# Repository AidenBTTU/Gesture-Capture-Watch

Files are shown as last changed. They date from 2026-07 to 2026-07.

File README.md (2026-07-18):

# Gesture-Capture-Watch
A wristband-mounted gesture recognition system built around an STM32F411, IMU, and OLED display, with USB-C battery charging and ESD-protected I/O. Includes full PCB design, manufacturing files, and firmware for real-time motion capture and on-device gesture classification via TFLite Micro. 

# Hardware Overview
- **MCU:** [STM32F411CEU6](https://www.st.com/en/microcontrollers-microprocessors/stm32f411.html), high Flash and SRAM to run TFLite model
- **IMU:** [LSM6DSOX](https://www.st.com/en/mems-and-sensors/lsm6dsox.html), industry standard, small form factor, low power consumption, includes a machine learning core for pre-processing
- **Power System:**
  - **Interface:** [USB-C](https://www.digikey.com/en/products/detail/gct/USB4105-GF-A-120/14559037), flexible power delivery, industry standard
  - **ESD Protection:** [USBLC6-2SC6](https://www.digikey.com/en/products/detail/stmicroelectronics/USBLC6-2SC6/1040559), industry standard
  - **Li-ion Battery Charger:** [BQ24092DGQR](https://www.ti.com/product/BQ24092/part-details/BQ24092DGQR), short circuit protection, variable charging
  - **Linear Regulator:** [TPS7A0533PDBZ](https://www.ti.com/product/TPS7A05/part-details/TPS7A0533PDBZT), low drop-out
- **Display:** 0.96" OLED display with SSD1306 chipset

# Software Overview (WIP)
- **Programming Environment:** STM32 programmed and configured via STLink V2. STM32CubeIDE was used to write code in C, and STM32CubeMX was used to set up peripherals and the external high-speed clock.
- **Libraries:** [u8g2](https://github.com/olikraus/u8g2), [lsm6dsox](https://github.com/STMicroelectronics/lsm6dsox-pid)

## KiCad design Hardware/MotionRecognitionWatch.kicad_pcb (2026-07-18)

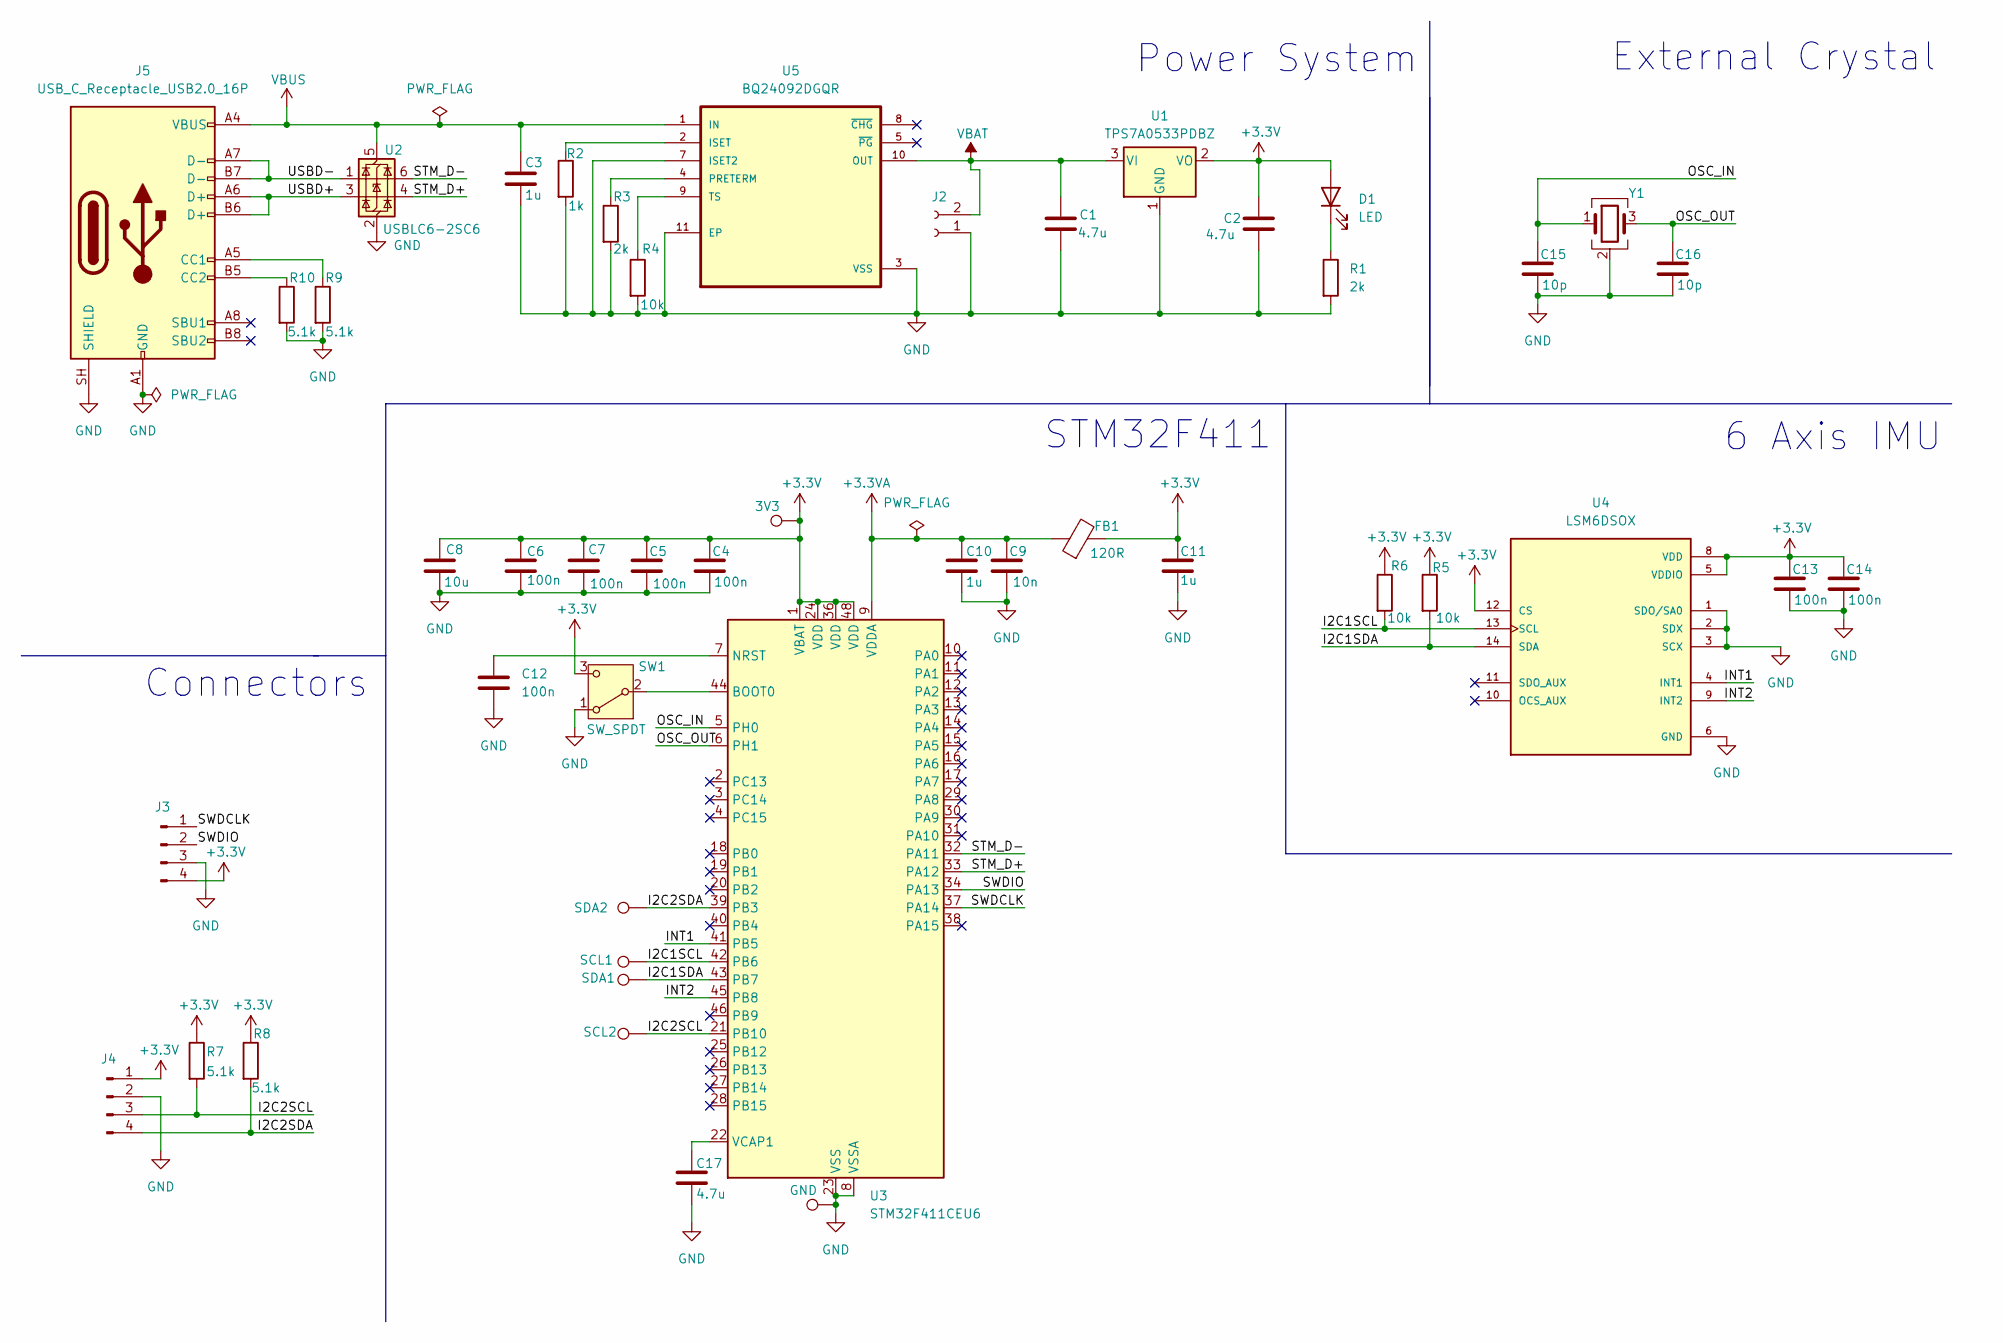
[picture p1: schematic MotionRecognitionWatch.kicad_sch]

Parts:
3V3: TestPoint; TestPoint_Pad_2.0x2.0mm
C1, C2, C17: 4.7u; C_0603_1608Metric
C3, C10, C11: 1u; C_0603_1608Metric
C4, C5, C6, C7, C12, C13, C14: 100n; C_0402_1005Metric
C8: 10u; C_0603_1608Metric
C9: 10n; C_0402_1005Metric
C15, C16: 10p; C_0402_1005Metric
D1: LED; LED_0603_1608Metric
FB1: 120R; L_0603_1608Metric
GND: TestPoint; TestPoint_Pad_2.0x2.0mm
J2: Conn_01x02_Socket; JST_PH_S2B-PH-K_1x02_P2.00mm_Horizontal
J3, J4: Conn_01x04_Pin; PinHeader_1x04_P2.54mm_Vertical
J5: USB_C_Receptacle_USB2.0_16P; USB_C_Receptacle_GCT_USB4105-xx-A_16P_TopMnt_Horizontal
R1, R3: 2k; R_0402_1005Metric
R2: 1k; R_0402_1005Metric
R4, R5, R6: 10k; R_0402_1005Metric
R7, R8, R9, R10: 5.1k; R_0402_1005Metric
SCL1, SCL2: TestPoint; TestPoint_Pad_2.0x2.0mm
SDA1: TestPoint; TestPoint_Pad_2.0x2.0mm
SDA2: TestPoint_Pad_2.0x2.0mm
SW1: SW_SPDT; SW_SPDT_PCM12
U1: TPS7A0533PDBZ; SOT-23
U2: USBLC6-2SC6; SOT-23-6
U3: STM32F411CEU6; QFN-48-1EP_7x7mm_P0.5mm_EP5.6x5.6mm
U4: LSM6DSOX; PQFN50P250X300X86-14N; PARTREV 3.0
U5: BQ24092DGQR; IC_XTR111AIDGQR
Y1: Crystal_GND24; Crystal_SMD_3225-4Pin_3.2x2.5mm

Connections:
+3.3V: 3V3.1 (1_1), C2.1, C4.1, C5.1, C6.1, C7.1, C8.1, C11.1, C13.1, C14.1, D1.2 (A), FB1.2, J3.4, J4.1, R5.1, R6.1, R7.1, R8.1, SW1.3 (C), U1.2 (VO), U3.1 (VBAT), U3.24 (VDD), U3.36 (VDD), U3.48 (VDD), U4.5 (VDDIO), U4.8 (VDD), U4.12 (CS); also elsewhere on the board
+3.3VA: C9.1, C10.1, FB1.1, U3.9 (VDDA)
/I2C1SCL: R6.2, SCL1.1 (1_1), U3.42 (PB6), U4.13 (SCL); also elsewhere on the board
/I2C1SDA: R5.2, SDA1.1 (1_1), U3.43 (PB7), U4.14 (SDA); also elsewhere on the board
/I2C2SCL: J4.3, R7.2, SCL2.1 (1_1), U3.21 (PB10)
/I2C2SDA: J4.4, R8.2, SDA2.1 (1_1), U3.39 (PB3)
/INT1: U3.41 (PB5), U4.4 (INT1); also elsewhere on the board
/INT2: U3.45 (PB8), U4.9 (INT2); also elsewhere on the board
/OSC_IN: C15.1, U3.5 (PH0), Y1.1
/OSC_OUT: C16.1, U3.6 (PH1), Y1.3
/STM_D+: U2.4 (I/O2), U3.33 (PA12)
/STM_D-: U2.6 (I/O1), U3.32 (PA11)
/SWDCLK: J3.1, U3.37 (PA14)
/SWDIO: J3.2, U3.34 (PA13)
/USBD+: J5.A6 (D+), J5.B6 (D+), U2.3 (I/O2)
/USBD-: J5.A7 (D-), J5.B7 (D-), U2.1 (I/O1)
GND: C1.2, C2.2, C3.2, C4.2, C5.2, C6.2, C7.2, C8.2, C9.2, C10.2, C11.2, C12.2, C13.2, C14.2, C15.2, C16.2, C17.2, GND.1 (1_1), J2.1, J3.3, J4.2, J5.A1 (GND), J5.A12 (GND), J5.B1 (GND), J5.B12 (GND), J5.SH (SHIELD), R1.2, R2.2, R3.2, R4.2, R9.2, R10.2, SW1.1 (A), U1.1 (GND), U2.2 (GND), U3.8 (VSSA), U3.23 (VSS), U3.35 (VSS), U3.47 (VSS), U3.49 (VSS), U4.1 (SDO/SA0), U4.2 (SDX), U4.3 (SCX), U4.6 (GND), U4.7 (GND), U5.3 (VSS), U5.7 (ISET2), U5.11 (EP), U5.12, U5.13, U5.14, U5.15, U5.16, Y1.2 (G), Y1.4 (G); also elsewhere on the board
unnamed: D1.1 (K), R1.1
unnamed: J5.A5 (CC1), R9.1
unnamed: J5.B5 (CC2), R10.1
unnamed 20: SW1.2 (B), U3.44 (BOOT0); also elsewhere on the board
unnamed: C12.1, U3.7 (NRST)
unnamed: C17.1, U3.22 (VCAP1)
unnamed: R2.1, U5.2 (ISET)
unnamed: R3.1, U5.4 (PRETERM)
unnamed: R4.1, U5.9 (TS)
VBAT: C1.1, J2.2, U1.3 (VI), U5.10 (OUT)
VBUS: C3.1, J5.A4 (VBUS), J5.A9 (VBUS), J5.B4 (VBUS), J5.B9 (VBUS), U2.5 (VBUS), U5.1 (IN)

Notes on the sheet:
STM32F411
Power System
Connectors
6 Axis IMU
External Crystal

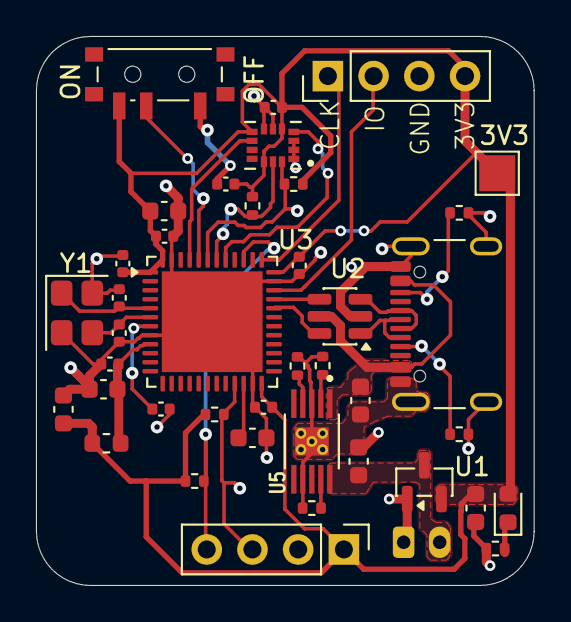
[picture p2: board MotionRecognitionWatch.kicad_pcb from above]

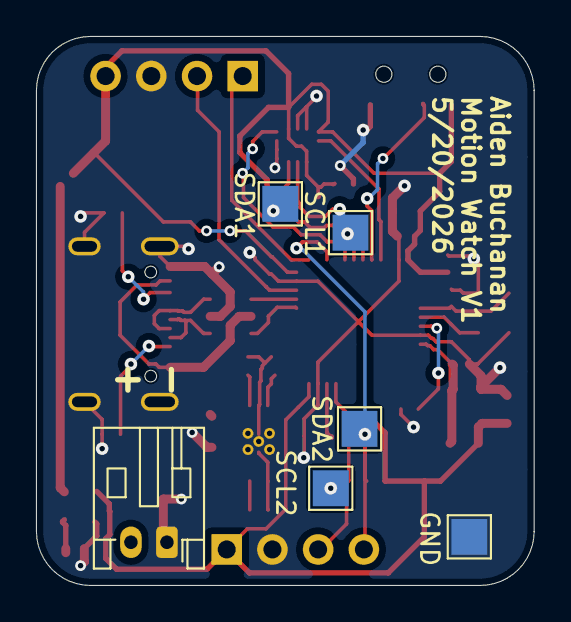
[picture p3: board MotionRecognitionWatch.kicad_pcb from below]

Board: 2 copper layers, 27.6 x 30.5 mm, 46 parts (6 on the bottom side), 28 nets.

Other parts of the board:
ON: SW_SPDT; SW_SPDT_PCM12
U6: LSM6DSOX; PQFN50P250X300X86-14N

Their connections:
+3.3V: ON.3 (C), U6.5 (VDDIO), U6.8 (VDD), U6.12 (CS); also elsewhere on the board
/I2C1SCL: U6.13 (SCL); also elsewhere on the board
/I2C1SDA: U6.14 (SDA); also elsewhere on the board
/INT1: U6.4 (INT1); also elsewhere on the board
/INT2: U6.9 (INT2); also elsewhere on the board
GND: ON.1 (A), U6.1 (SDO/SA0), U6.2 (SDX), U6.3 (SCX), U6.6 (GND), U6.7 (GND); also elsewhere on the board
unnamed 20: ON.2 (B); also elsewhere on the board

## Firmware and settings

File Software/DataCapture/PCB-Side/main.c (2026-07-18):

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
/* Includes ------------------------------------------------------------------*/
#include "main.h"
#include "usb_device.h"

/* USER CODE BEGIN Includes */
#include "lsm6dsox_reg.h"
#include "usbd_cdc_if.h"
#include <stdio.h>
#include <stdint.h>
#include <stddef.h>
#include <math.h>
#include <string.h>
#include "u8g2.h"
/* USER CODE END Includes */

I2C_HandleTypeDef hi2c1;
I2C_HandleTypeDef hi2c2;

void SystemClock_Config(void);
static void MX_GPIO_Init(void);
static void MX_I2C1_Init(void);
static void MX_I2C2_Init(void);
/* USER CODE BEGIN PFP */
#define LSM6DSOX_I2C_ADDR (0x6A << 1)
#define DISPLAY_ADDR (0x3C << 1)

/* USER CODE END PFP */

/* USER CODE BEGIN 0 */
static uint8_t i2c_tx_buf[256];
static uint8_t i2c_tx_buf_idx = 0;
uint8_t u8x8_byte_stm32_hw_i2c(u8x8_t *u8x8, uint8_t msg, uint8_t arg_int, void *arg_ptr)
{
	uint8_t *data;
	    switch(msg)
	    {
	        case U8X8_MSG_BYTE_INIT:
	            break; // HAL I2C already initialized in MX_I2C2_Init

	        case U8X8_MSG_BYTE_START_TRANSFER:
	            i2c_tx_buf_idx = 0;
	            break;

	        case U8X8_MSG_BYTE_SEND:
	            data = (uint8_t *)arg_ptr;
	            while(arg_int > 0) {
	                i2c_tx_buf[i2c_tx_buf_idx++] = *data++;
	                arg_int--;
	            }
	            break;

	        case U8X8_MSG_BYTE_END_TRANSFER:
	        	HAL_I2C_Master_Transmit(
	                &hi2c2,
	                DISPLAY_ADDR,
	                i2c_tx_buf,
	                i2c_tx_buf_idx,
	                1000    
				);
	            break;

	        default:
	            return 0;
	    }
	    return 1;
}

uint8_t u8x8_delay_and_gpio(u8x8_t *u8x8, uint8_t msg, uint8_t arg_int, void *arg_ptr) {
switch(msg)
    {
        case U8X8_MSG_GPIO_AND_DELAY_INIT:
            break; 

        case U8X8_MSG_GPIO_RESET:
            break; 

        case U8X8_MSG_DELAY_MILLI:
            HAL_Delay(arg_int);
            break;

        case U8X8_MSG_DELAY_10MICRO:
            // 72MHz → ~720 cycles per 10µs; loop overhead ~5 cyc/iter → 144 iters
            for(uint8_t d = 0; d < arg_int; d++)
                for(volatile uint32_t i = 0; i < 144; i++) __NOP();
            break;

        case U8X8_MSG_DELAY_100NANO:
            for(uint8_t d = 0; d < arg_int; d++) {
                __NOP(); __NOP(); __NOP(); __NOP(); __NOP(); __NOP(); __NOP();
            }
            break;

        default:
            return 0;
    }
    return 1;
}
/* USER CODE END 0 */

/**
  * @brief  The application entry point.
  * @retval int
  */
int main(void)
{

  /* MCU Configuration--------------------------------------------------------*/

  /* Reset of all peripherals, Initializes the Flash interface and the Systick. */
  HAL_Init();

  /* Configure the system clock */
  SystemClock_Config();

  /* Initialize all configured peripherals */
  MX_GPIO_Init();
  MX_I2C1_Init();
  MX_I2C2_Init();
  MX_USB_DEVICE_Init();
  /* USER CODE BEGIN 2 */
  stmdev_ctx_t dev_ctx;

  dev_ctx.write_reg = platform_write;
  dev_ctx.read_reg = platform_read;
  dev_ctx.handle = &hi2c1;


  /* USER CODE END 2 */

  /* Infinite loop */
  /* USER CODE BEGIN WHILE */
  uint8_t whoami;
  lsm6dsox_device_id_get(&dev_ctx, &whoami);
  lsm6dsox_reset_set(&dev_ctx, PROPERTY_ENABLE);

  uint8_t rst;
  do {
      lsm6dsox_reset_get(&dev_ctx, &rst);
  } while (rst);

  lsm6dsox_block_data_update_set(&dev_ctx, PROPERTY_ENABLE);

  lsm6dsox_xl_data_rate_set(
      &dev_ctx,
      LSM6DSOX_XL_ODR_104Hz);

  lsm6dsox_xl_full_scale_set(
      &dev_ctx,
      LSM6DSOX_2g);

  lsm6dsox_gy_data_rate_set(
      &dev_ctx,
      LSM6DSOX_GY_ODR_104Hz);

  lsm6dsox_gy_full_scale_set(
      &dev_ctx,
      LSM6DSOX_250dps);



  u8g2_t u8g2; 
  u8g2_Setup_ssd1306_i2c_128x64_noname_f(&u8g2, U8G2_R0, u8x8_byte_stm32_hw_i2c, u8x8_delay_and_gpio);
  u8g2_InitDisplay(&u8g2);
  u8g2_SetPowerSave(&u8g2, 0);
  u8g2_SetFont(&u8g2, u8g2_font_6x10_tf);   
  u8g2_ClearBuffer(&u8g2);

  HAL_Delay(500);

  volatile int16_t gyro_raw[3];
  volatile int16_t accel_raw[3];

  while (1)
  {
    /* USER CODE END WHILE */

    /* USER CODE BEGIN 3 */

	  //Check if ready to receive data
      uint8_t xl_ready;
      uint8_t gy_ready;
      lsm6dsox_xl_flag_data_ready_get(&dev_ctx, &xl_ready);
      lsm6dsox_gy_flag_data_ready_get(&dev_ctx, &gy_ready);

      if (xl_ready && gy_ready)
      {
    	  //Poll values, pass into USB
          lsm6dsox_acceleration_raw_get(&dev_ctx, (int16_t *)accel_raw);
          lsm6dsox_angular_rate_raw_get(&dev_ctx, (int16_t *)gyro_raw);

          int32_t ax = ((int32_t)accel_raw[0] * 61) / 1000;
          int32_t ay = ((int32_t)accel_raw[1] * 61) / 1000;
          int32_t az = ((int32_t)accel_raw[2] * 61) / 1000;

          char line[24];
          u8g2_ClearBuffer(&u8g2);

          snprintf(line, sizeof(line), "AX: %4d mg", (int)ax);
          u8g2_DrawStr(&u8g2, 0, 12, line);

          snprintf(line, sizeof(line), "AY: %4d mg", (int)ay);
          u8g2_DrawStr(&u8g2, 0, 26, line);

          snprintf(line, sizeof(line), "AZ: %4d mg", (int)az);
          u8g2_DrawStr(&u8g2, 0, 40, line);

          u8g2_SendBuffer(&u8g2);
          char tx_buf[64];
          int len = snprintf(tx_buf, sizeof(tx_buf),
                    "%d,%d,%d,%d,%d,%d\r\n",
                    (int)accel_raw[0], (int)accel_raw[1], (int)accel_raw[2],
                    (int)gyro_raw[0],  (int)gyro_raw[1],  (int)gyro_raw[2]);

          CDC_Transmit_FS((uint8_t *)tx_buf, (uint16_t)len);



      }

      HAL_Delay(100);
  }
  /* USER CODE END 3 */
}

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
/* USER CODE BEGIN 4 */
int32_t platform_write(
    void *handle,
    uint8_t reg,
    const uint8_t *bufp,
    uint16_t len)
{
    HAL_I2C_Mem_Write(
        (I2C_HandleTypeDef*)handle,
        LSM6DSOX_I2C_ADDR,
        reg,
        I2C_MEMADD_SIZE_8BIT,
        (uint8_t*)bufp,
        len,
        1000);

    return 0;
}

int32_t platform_read(
    void *handle,
    uint8_t reg,
    uint8_t *bufp,
    uint16_t len)
{
    HAL_I2C_Mem_Read(
        (I2C_HandleTypeDef*)handle,
        LSM6DSOX_I2C_ADDR,
        reg,
        I2C_MEMADD_SIZE_8BIT,
        bufp,
        len,
        1000);

    return 0;
}


/* USER CODE END 4 */
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


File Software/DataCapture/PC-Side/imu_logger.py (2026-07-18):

#!/usr/bin/env python3
"""
imu_logger.py

Reads raw IMU data ("ax,ay,az,gx,gy,gz\r\n") streamed from the STM32's
USB CDC virtual COM port, prints each sample to the console, and logs
every sample (with a host-side timestamp) to a CSV file.

Usage:
    python imu_logger.py --port COM5
    python imu_logger.py --port /dev/ttyACM0 --out session1.csv
    python imu_logger.py --list                # list available serial ports

Install dependency once:
    pip install pyserial
"""

import argparse
import csv
import sys
import time
from datetime import datetime

import serial
import serial.tools.list_ports


def list_ports():
    ports = list(serial.tools.list_ports.comports())
    if not ports:
        print("No serial ports found.")
        return
    print("Available serial ports:")
    for p in ports:
        print(f"  {p.device} - {p.description}")


def guess_port():
    """Try to find a likely STM32 virtual COM port automatically."""
    candidates = list(serial.tools.list_ports.comports())
    for p in candidates:
        desc = (p.description or "").lower()
        if "stm" in desc or "virtual com" in desc or "cdc" in desc:
            return p.device
    return candidates[0].device if candidates else None


def parse_line(raw_line: str):
    """Parse 'ax,ay,az,gx,gy,gz' -> tuple of 6 ints, or None if malformed."""
    parts = raw_line.strip().split(",")
    if len(parts) != 6:
        return None
    try:
        return tuple(int(p) for p in parts)
    except ValueError:
        return None


def main():
    parser = argparse.ArgumentParser(description="Log IMU data from STM32 USB CDC to CSV.")
    parser.add_argument("--port", help="Serial port (e.g. COM5 or /dev/ttyACM0). "
                                        "If omitted, the script will try to auto-detect.")
    parser.add_argument("--baud", type=int, default=115200,
                         help="Baud rate (ignored by USB CDC but required by pyserial). Default 115200.")
    parser.add_argument("--out", default=None,
                         help="Output CSV filename. Default: imu_log_<timestamp>.csv")
    parser.add_argument("--list", action="store_true", help="List available serial ports and exit.")
    args = parser.parse_args()

    if args.list:
        list_ports()
        return

    port = args.port or guess_port()
    if not port:
        print("Could not find a serial port automatically. Run with --list to see options, "
              "then pass --port <name>.")
        sys.exit(1)

    out_path = args.out or f"imu_log_{datetime.now().strftime('%Y%m%d_%H%M%S')}.csv"

    print(f"Opening {port} @ {args.baud} baud...")
    try:
        ser = serial.Serial(port, args.baud, timeout=1)
    except serial.SerialException as e:
        print(f"Failed to open serial port {port}: {e}")
        sys.exit(1)

    # Let the port settle (helps on some platforms after open/reset)
    time.sleep(0.5)
    ser.reset_input_buffer()

    print(f"Logging to {out_path}")
    print("Columns: timestamp, ax_raw, ay_raw, az_raw, gx_raw, gy_raw, gz_raw")
    print("Press Ctrl+C to stop.\n")

    sample_count = 0
    bad_count = 0

    try:
        with open(out_path, "w", newline="") as f:
            writer = csv.writer(f)
            writer.writerow(["timestamp", "ax_raw", "ay_raw", "az_raw",
                              "gx_raw", "gy_raw", "gz_raw"])
            f.flush()

            while True:
                try:
                    raw = ser.readline().decode("utf-8", errors="replace")
                except UnicodeDecodeError:
                    continue

                if not raw:
                    continue  # timeout with no data, just loop again

                values = parse_line(raw)
                if values is None:
                    bad_count += 1
                    # Uncomment to debug malformed lines:
                    # print(f"[skipped malformed line]: {raw!r}")
                    continue

                timestamp = datetime.now().isoformat(timespec="milliseconds")
                ax, ay, az, gx, gy, gz = values

                print(f"{timestamp}  AX={ax:6d} AY={ay:6d} AZ={az:6d} "
                      f"GX={gx:6d} GY={gy:6d} GZ={gz:6d}")

                writer.writerow([timestamp, ax, ay, az, gx, gy, gz])
                f.flush()  # write-through so data isn't lost if interrupted

                sample_count += 1

    except KeyboardInterrupt:
        print("\nStopped by user.")
    finally:
        ser.close()
        print(f"\nSamples logged: {sample_count}")
        if bad_count:
            print(f"Malformed lines skipped: {bad_count}")
        print(f"CSV saved to: {out_path}")


if __name__ == "__main__":
    main()

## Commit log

2026-07-18 Added KiCad files for PCB and Schematic
    [MotionRecognitionWatch.kicad_pcb, MotionRecognitionWatch.kicad_sch]
2026-07-18 Add main.c for PCB data capture functionality

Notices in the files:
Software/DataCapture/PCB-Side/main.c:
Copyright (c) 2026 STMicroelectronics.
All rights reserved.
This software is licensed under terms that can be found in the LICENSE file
